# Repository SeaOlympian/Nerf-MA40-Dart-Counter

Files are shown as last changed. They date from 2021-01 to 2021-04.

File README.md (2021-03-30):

# Nerf-MA40-Dart-Counter
Nerf blaster visual dart counter and clip capacity detector.

Please note that this project was created as a senior project and for fun therefore I will not be able to help answer any questions or fix any problems that may arise. I also take no responsibility if you damage you blaster or injure yourself by modifying it.

---

## Parts List:
  - One Arduino compatible board of some kind (I used a Teensy 3.2. See why below)
  - Two [Hall Effect sensors](https://www.amazon.com/gp/product/B07QS6PN3B/ref=ppx_yo_dt_b_asin_title_o05_s00?ie=UTF8&psc=1)
  - One [I2C OLED Screen](https://www.amazon.com/gp/product/B0761LV1SD/ref=ppx_yo_dt_b_asin_title_o05_s01?ie=UTF8&psc=1)
  - One microswitch/limit switch
  - One Capacitor (I used a 100µF that I had laying around)
  - Micro USB to USB Type C adapter (Optional)
  - Screen Frame (Optional. Files in the Models folder)

## Explanition/Details:
<p>The basic idea of this mod is to use two hall effect sensors to read what magnets are attached to the dart magazines. That tells the microcontroller how many darts are in them which is then displayed on the screen. When the trigger is pulled it activates the microswitch which tells the microcontroller there is one less dart in the magazine and again updates the screen.</p>

Hall Effect Sensors: When a magnet is in front of them their output changes from 1 to 0. The program uses pins 14 and 15 for their outputs.

I2C OLED Screen: I used a blue screen as the origional counter is blue. I also changed the default I2C pins on the Teensy to pins 16 and 17.

Microswitch: The program uses pin 13.

Capacitor: This is used to prevent the current draw of the flywheels to cause a brown out of the microcontroller making it reset. It is wired in parallel with the power for the microcontroller.

Screen Frame: I designed this frame to hold the OLED screen in place and fill the area around it. I 3D printed it in black so that it blends in better. It fits inside the clear plastic panel in the origional housing and replaces the fake screen.

## Why did I use a Teensy 3.2?
There are two reasons why I decided to use a Teensy 3.2
  - It's Vin accepts 3.6 to 6.0 volts. This allows it to be use directly off of the four C batteries without the need for a voltage regulating circuit.
  - I already had one laying around.

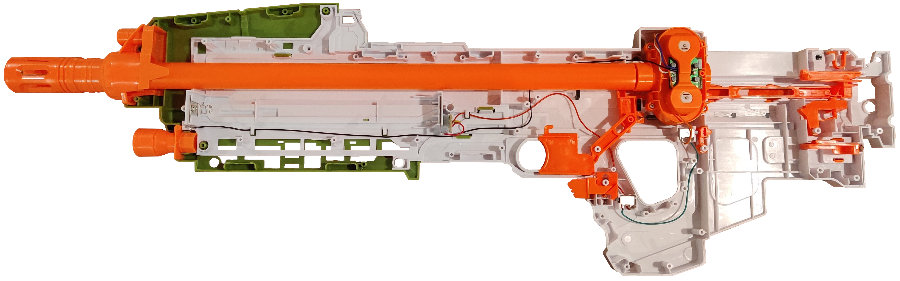
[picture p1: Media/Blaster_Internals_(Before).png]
Blaster Internals Before
  
  <p>Take a good look at where the pieces of the blaster are such as the trigger and magazine catch. Also take the time to figure out where you want to put the power switch and microcontroller. I wanted the power switch somewhere it could not be easily bumped and wanted to be able to update the code on my Teensy without tearning the whole blaster apart again.</p>

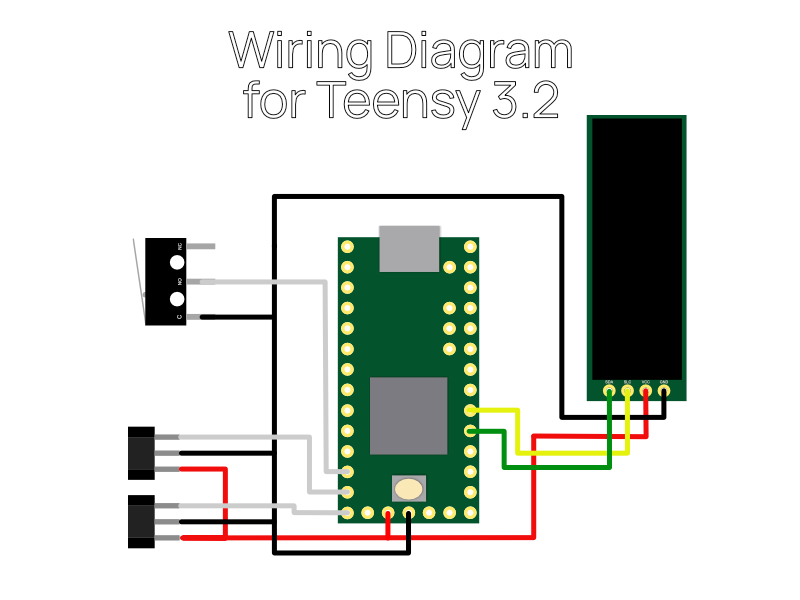
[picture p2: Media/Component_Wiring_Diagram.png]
Teensy 3.2 Wiring Diagram
  
  <p>Because of the location I wanted to put the Teensey I tried to wire everything towards the bottom of it. If you want to place it in a different location or are using a different microcontroller feel free to change the pins used.</p>

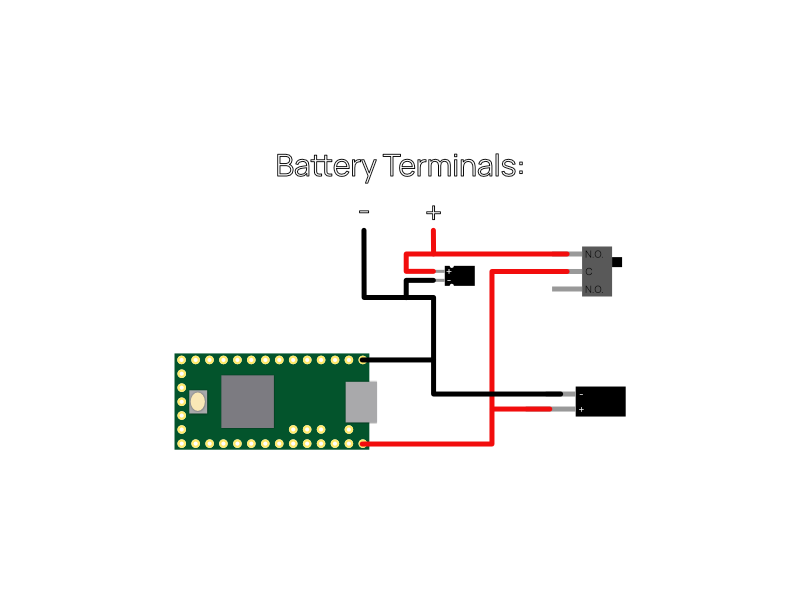
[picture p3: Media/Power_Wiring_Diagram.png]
Power Wiring Diagram
  
  <p>I ran into a problem after I finished everything where the fly wheels would draw too much current when a dart went through them causing the Teensy to restart. So in order to fix the problem I added a 100µF capacitor as a temporary resivoir to keep the Teensy running for those short moments.</p>

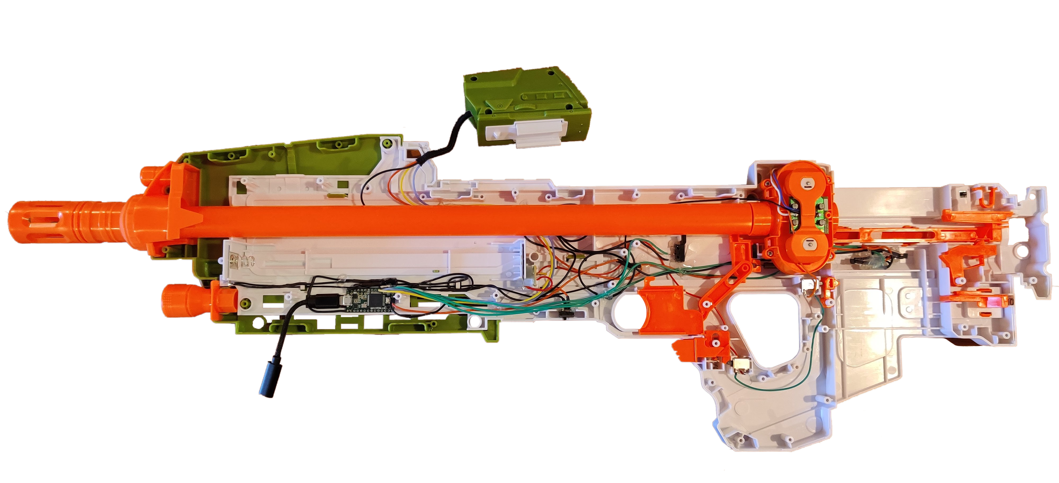
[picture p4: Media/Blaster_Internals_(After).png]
Blaster Internals After
  
  <p>This is what it looked like after all the wiring and cutting was done. A bit messy but it was the best use of space that in my opinion and everything stays out of the way of the top half of the shell. Having the Teensy basically inside the handguard also means I need to only take that apart to update the code if necessary espically with the help of the micro USB to type C adapter.</p>

  USB Adapter
  <p>Here is a close up of how I routed the usb adapter so it is more easily accessible.</p>

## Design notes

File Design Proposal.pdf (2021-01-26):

ETEM 2520 - Design Lab 1

Project Proposal

Part Quantity Selector and Counter

Spring 2021

Proposal Abstract

The proposal for this design project is an automated system that selects the proper part

quantity and then counts down as the parts are used. The system will have a display showing the

remaining number of parts in the bin as well as indicate when the parts container is empty.

System Design Description

The system being proposed will consist of a microcontroller, display screen, micro

switch, power switch, and hall effect sensors. Magnets attached to the parts containers will be

sensed by the hall effect sensors which will tell the microcontroller the quantity of the parts

which will be displayed on the screen. Every time the micro switch is triggered the

microcontroller will decrement the total by one and update the display. The display will also

indicate when the container is empty and will not reset until a new container is inserted into the

system. The block diagram of the proposed system can be seen in Figure one.

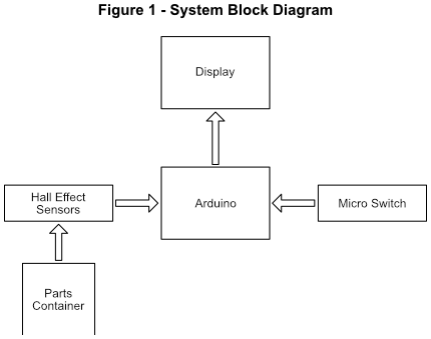
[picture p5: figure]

Bill of Materials

Item | Description | Qty. | Unit Price | Ext. Price
1 | Teensy 3.2 | 1 | $19.80 | $19.80
2 | I2C OLED Screen (Blue) | 1 | $4.99 | $4.99
3 | Micro Switch | 1 | $2.95 | $2.95
4 | Power Switch | 1 | $0.95 | $0.95
5 | Hall Effect Sensor | 2 | $0.36 | $0.73
Total: | | | | $29.42

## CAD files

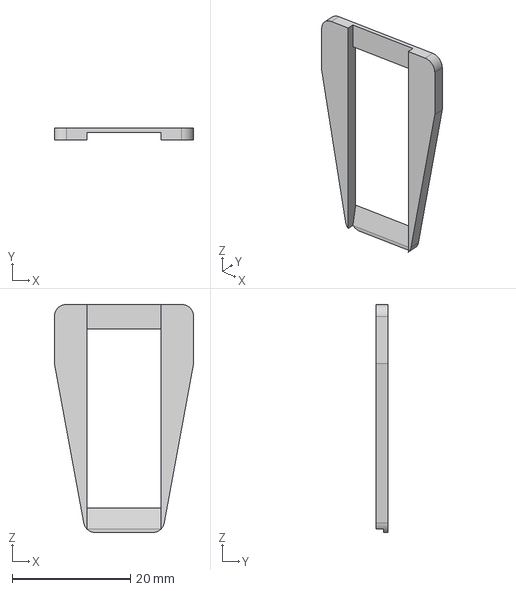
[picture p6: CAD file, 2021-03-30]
Models/Screen_Frame.step
23.5 x 2.00 x 38.5 mm

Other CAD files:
Models/Screen_Frame.stl

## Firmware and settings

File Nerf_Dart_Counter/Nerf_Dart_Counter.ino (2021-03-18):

#include <SPI.h>
#include <Wire.h>
#include <Adafruit_GFX.h>
#include <Adafruit_SSD1306.h>
#include <JC_Button.h>

//Set to true to debug.
bool Debug = false;

int Hall_Pin_1 = 14;
int Hall_Pin_2 = 15;

//Uses JC_Button to create a button with debouncing.
Button Switch(13);

//Maximum number of darts in mag.
int dartMax;
//Current number of darts in mag.
int dartCurrent;
//State of the mag, 1 if empty, 0 if there are darts.
int magEmpty = 0;

#define SCREEN_WIDTH 128 // OLED display width, in pixels
#define SCREEN_HEIGHT 32 // OLED display height, in pixels

// Declaration for an SSD1306 display connected to I2C (SDA, SCL pins)
// The pins for I2C are defined by the Wire-library. 
#define OLED_RESET     4 // Reset pin # (or -1 if sharing Arduino reset pin)
Adafruit_SSD1306 display(SCREEN_WIDTH, SCREEN_HEIGHT, &Wire, OLED_RESET);

//Compass Bitmap
#define compass_height 16
#define compass_width 10
static const unsigned char PROGMEM compass_bmp[] =
{ 0x00, 0x00, 0x0c, 0x00, 0x0c, 0x00, 0x0c, 0x00, 0x1e, 0x00, 0x1e, 0x00, 0x1e, 0x00, 0x3f, 0x00, 
0x3f, 0x00, 0x3f, 0x00, 0x7f, 0x80, 0x7f, 0x80, 0x7f, 0x80, 0xff, 0xc0, 0x00, 0x00, 0x1e, 0x00 };

//Dart Icon Bitmap
#define dart_height 7
#define dart_width 20
static const unsigned char PROGMEM dart_bmp[] =
{ 0x50, 0x00, 0x00, 0xd9, 0xff, 0xe0, 0x03, 0x00, 0x70, 0x03, 0x00, 0x70, 0x03, 0x00, 0x70, 0xd9, 
0xff, 0xe0, 0x50, 0x00, 0x00 };

void setup() {
  Serial.begin(9600);

  pinMode(Hall_Pin_1, INPUT_PULLUP);
  pinMode(Hall_Pin_2, INPUT_PULLUP);

  Wire.setSDA(17);
  Wire.setSCL(16);


  //Creates instance of button with the name Switch.
  Switch.begin();

  // SSD1306_SWITCHCAPVCC = generate display voltage from 3.3V internally
  if(!display.begin(SSD1306_SWITCHCAPVCC, 0x3C)) { // Address 0x3C for 128x32
    Serial.println(F("SSD1306 allocation failed"));
    for(;;); // Don't proceed, loop forever
  }

  //Rotates the display 90 degrees.
  display.setRotation(1);

  // Show initial display buffer contents on the screen --
  // the library initializes this with an Adafruit splash screen.
  display.display();
  delay(2000); // Pause for 2 seconds

  // Clear the buffer
  display.clearDisplay();

}

void loop() {
  display.clearDisplay();
  
  magCheck();     //Selects the magazine size.
  drawCompassBitmap();
  drawDartBitmap();
  trigger();    //Decrements the current dart count.
  dartCount();    //Displays the current dart count.

  //Prints out hall effect sensor readings and dart maximum if debug is enabled.
  if (Debug){   
    Serial.print("Sensor One: ");
    Serial.println(digitalRead(Hall_Pin_1));

    Serial.print("Sensor Two: ");
    Serial.println(digitalRead(Hall_Pin_2));

    Serial.print("Dart Total: ");
    Serial.println(dartMax);
    };
    
    display.display();
}

//----------FUNCTIONS----------

void drawCompassBitmap(void)
{
  display.drawBitmap(
    (display.width() - compass_width) / 2,
    5, compass_bmp, compass_width, compass_height, 1);
  //display.display();
}

//--------------------

void drawDartBitmap(void)
{
  display.drawBitmap(
    (display.width() - dart_width) / 2,
    110, dart_bmp, dart_width, dart_height, 1);
  //display.display();
}

//--------------------

void magCheck(){
  //Checks states of hall effect sensors and determines correct mag size.
  if (digitalRead(Hall_Pin_1) == 0 && digitalRead(Hall_Pin_2) == 1)
    dartMax = 10;
  else if (digitalRead(Hall_Pin_1) == 1 && digitalRead(Hall_Pin_2) == 0)
    dartMax = 6;
  else if (digitalRead(Hall_Pin_1) == 1 && digitalRead(Hall_Pin_2) == 1){
    dartMax = 0;
    magEmpty = 1;
  }

  //Checks to see of the current dart count should be reset.
  if (magEmpty == 1 && dartMax !=0){
    dartCurrent = dartMax;
    magEmpty = 0;
  }
}

//--------------------

void trigger(){
  //Recordes the state of the switch.
  Switch.read();

  if (Switch.wasReleased() && dartCurrent != 0)
    dartCurrent--;
}

//--------------------

void dartCount() {
  display.setTextSize(2);      // Normal 1:1 pixel scale
  display.setTextColor(SSD1306_WHITE); // Draw white text

  //Display countdown
  if (dartCurrent >= 10)
    display.setCursor(5,  60);      //Selects cursor position based on number of characters.
  else
      display.setCursor(11, 60);
  if (dartMax != 0)
    display.println(dartCurrent);     //Prints current number of darts to display if there is a mag.
  else{
    display.setCursor(5,  60);
    display.println("--");
  }
  //display.display();
}

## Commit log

2021-01-26 Added starting arduino code file.
2021-02-02 Added additional graphics
    Added graphical images files and implemented their display in the main arduino code.
2021-02-24 Added Wiring Diagram
    Added a wiring diagram and the accompanying files.
2021-02-24 Updated ReadMe
    Added wiring diagram to the readme.
2021-03-11 Readme work
    Added headers and reasons I used a Teensy 3.2.
2021-03-12 Replaced switch images
2021-03-14 Corrected Wiring Diagram & Readme
2021-03-18 Updated I2C Pins
    Changed the pins for I2C.
2021-03-30 Added models
    Added stl and step files for the screen frame.
    [Screen_Frame.step, Screen_Frame.stl]
2021-04-12 Updated diagram
    Added the capacitor to the diagram.
